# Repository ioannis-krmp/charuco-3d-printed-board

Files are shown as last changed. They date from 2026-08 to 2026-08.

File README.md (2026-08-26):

# Charuco 3D Printed Board

3D-printable CharUco board workflow with:
- PNG board generation (OpenCV ArUco/CharUco)
- CAD solid generation (FreeCAD)
- STEP export for design editing
- 2-color STL workflow for multi-material printing
- Calibration YAML for OpenCV pose estimation

## Board Spec (current project)

- Board squares: **14 x 10** (`squares_x=14`, `squares_y=10`)
- Square size: **20.0 mm**
- Marker size: **15.0 mm**
- Dictionary: **`DICT_5X5_100`**
- Physical size: **280 x 200 mm**
- Thickness: **2.5 mm**

---

## Setup (Ubuntu 24.04)

This project uses two separate Python runtimes:

- **`uv`-managed venv** — for `gen_png.py` (OpenCV) and the CadQuery scripts (`colorize_step_cq.py`, `export_glb.py`). Run these with `uv run python <script>.py`.
- **FreeCAD's own bundled Python** — for `build_step.py`, `build_stl.py`, `build_step_colored.py`, since they `import FreeCAD, Part, Mesh` (and `ImportGui`), which are not pip-installable and only exist inside FreeCAD itself. Run these with `freecadcmd <script>.py`, **not** `uv run`.

### 1) Install system dependencies

```bash
# git, if not already installed
sudo apt update
sudo apt install -y git

# FreeCAD 0.21 (provides the `freecadcmd` binary used below)
sudo add-apt-repository ppa:freecad-maintainers/freecad-stable
sudo apt update
sudo apt install -y freecad
```

> The Ubuntu 24.04 `universe` repo also ships a `freecad` package, but the PPA above is what this project was built and tested against (`FreeCAD 0.21.2`). If you already have a working FreeCAD 0.21.x install (`freecadcmd --version`), you can skip the PPA.

Install `uv` (manages the Python venv + dependencies, no system Python packages needed):

```bash
curl -LsSf https://astral.sh/uv/install.sh | sh
# then restart your shell, or: source $HOME/.local/bin/env
```

`uv` will automatically download and use Python 3.11 (pinned in `.python-version`) — you don't need to install Python yourself.

### 2) Clone and install project dependencies

```bash
git clone git@github.com:ioannis-krmp/charuco-3d-printed-board.git
cd charuco-3d-printed-board
uv sync
```

`uv sync` creates `.venv/` and installs everything from `pyproject.toml`/`uv.lock`: `opencv-contrib-python`, `cadquery`, `manifold3d`, `numpy`, `trimesh`.

### 3) Verify the install

```bash
# venv deps
uv run python -c "import cv2, cadquery; print('cv2', cv2.__version__, '| cadquery', cadquery.__version__)"

# FreeCAD
freecadcmd --version
freecadcmd -c "import FreeCAD, Part, Mesh; print('FreeCAD OK', FreeCAD.Version()[0]+'.'+FreeCAD.Version()[1])"
```

If both commands print versions without errors, you're ready to run the pipeline below.

---

## Repository Structure

Suggested layout:

```text
.
├── gen_png.py
├── build_step.py
├── build_stl.py
├── build_step_colored.py
├── colorize_step_cq.py
├── export_glb.py
├── charuco_board.yaml
├── meta.txt
├── charuco.png
├── charuco_white.step
├── charuco_black.step
├── charuco_board.step
├── charuco_board_colored.step
├── charuco_board_colored.glb
├── charuco_board_step.FCStd
├── charuco_white.stl
├── charuco_black.stl
├── pyproject.toml
├── uv.lock
├── PROJECT_HISTORY.md
└── README.md
```

> You can also place outputs in `out/` if you prefer.
>
> `pyproject.toml`/`uv.lock` pin the `uv`-managed dependencies (see [Setup](#setup-ubuntu-2404)); `PROJECT_HISTORY.md` is a narrative log of what was tried, what failed, and why — read it if you hit one of the FreeCAD/color issues below and want the backstory.

---

## Quick Start (A)

Run these from the repo root, in this order. Board parameters (`SQUARES_X`, `SQUARE_LEN_MM`, `THICK_MM`, dictionary, etc.) are hardcoded near the top of each script — edit them there if you want a different board than the [current spec](#board-spec-current-project); just keep the values consistent across all scripts and the calibration YAML.

## 1) Generate board PNG + metadata

```bash
uv run python gen_png.py
```

Reads the parameters at the top of `gen_png.py` (14×10 squares, 20mm, `DICT_5X5_100`, 4 px/mm) and produces:
- `charuco.png` — the flat board image (1120×800 px for the current spec)
- `meta.txt` — 3 lines: pixel width, pixel height, pixels-per-mm (consumed by the FreeCAD scripts below)

## 2) Build CAD-editable STEP solids

```bash
freecadcmd build_step.py
```

Converts `charuco.png` into two complementary BREP solids (`white = full_slab - black`), cleans faces with `removeSplitter()`, and exports:
- `charuco_white.step`, `charuco_black.step` — individual solids
- `charuco_board.step` — both solids in one STEP assembly
- `charuco_board_step.FCStd` — editable FreeCAD document

**This is slow** — it's building thousands of per-pixel-run boxes and fusing them with `multiFuse`. Expect several minutes for a 14×10 board; it prints `row N/H` progress and `A:`…`J:` stage markers, so it's working even when it looks stuck. Let it finish.

## 3) Build STLs for 2-color printing

```bash
freecadcmd build_stl.py
```

Same complementary-solid geometry as step 2, but meshed and exported as STL, plus its own `.FCStd`:
- `charuco_white.stl`, `charuco_black.stl`
- `charuco_board.FCStd`

Also slow for the same reason as step 2 — this rebuilds the geometry from scratch rather than reusing the STEP output.

In your slicer:
- Load both STLs
- Keep same origin/alignment (they were exported from the same coordinate system, don't re-center either one)
- Assign White filament to `charuco_white.stl`, Black filament to `charuco_black.stl`
- Use **Print sequence: By layer**

## 4) Colored visualization exports (STEP + GLB)

STEP color via FreeCAD's console (`ImportGui`) doesn't work on a headless/console build — see [Troubleshooting #3](#3-importgui--color-export-fails-in-console). The working path is CadQuery, run through `uv`, using the STEP solids from step 2:

```bash
uv run python colorize_step_cq.py   # -> charuco_board_colored.step
uv run python export_glb.py         # -> charuco_board_colored.glb
```

`.glb` is the reliable one for checking color in a browser/web viewer — see [Troubleshooting #4](#4-step-shows-no-color-in-online-viewer) for why the colored STEP may still look gray in some viewers.

Optional — `freecadcmd build_step_colored.py` also exists and will get as far as saving a colored `charuco_board_colored.FCStd`, but is **expected to fail** on its final `ImportGui.export()` call with `Cannot load Gui module in console application`; that's a known FreeCAD console limitation, not a bug in the script (see [Troubleshooting #3](#3-importgui--color-export-fails-in-console) and `PROJECT_HISTORY.md`). Use it only if you want the colored `.FCStd`; use `colorize_step_cq.py` for the colored STEP itself.

## 5) Calibration YAML

Use:

```yaml
dict_type: DICT_5X5_100
reference_frame: charuco_board
squares_x: 14
squares_y: 10
square_size: 0.020
marker_size: 0.015
```

Keep `squares_x`/`squares_y`/`square_size`/`marker_size`/`dict_type` here in sync with whatever you set at the top of `gen_png.py` (note the unit difference: mm in the script, meters in the YAML).

---

## Printing Notes

- Recommended for AMS/MMU-style color swap:
  - White base + black pattern as separate solids
  - **By layer** printing
- Add brim for flatness on large plates
- Keep bed well-leveled; this is a metrology target
- Measure printed square size with calipers and, if needed, update YAML dimensions for precise calibration scale

---

## Troubleshooting (B)

## 1) First-layer geometry conflicts (slicer errors)

**Symptom:** "Some objects are too close", "virtual bed out of bounds", or bad 2-color merge.

**Cause:** Overlapping full slabs or duplicate bottoms.

**Fix:** Use complementary solids:
- `white = full_slab - black`
- `black = pattern`
No overlap, perfect interlock.

---

## 2) FreeCAD script is very slow

**Symptom:** `multiFuse` appears stuck for minutes.

**Cause:** Thousands of pixel-run boxes.

**Fixes:**
- Let it finish (expected for large boards)
- Keep `removeSplitter()` to clean faces
- Consider faster geometry strategy (face/contour extrusions) for large designs

---

## 3) `ImportGui` / color export fails in console

**Symptom:** `Cannot load Gui module in console application.`

**Cause:** Your FreeCAD console build cannot load GUI module in headless mode.

**Fix:**
- Use CadQuery/OCP route for colorized export, or
- Do color assignment + STEP export from FreeCAD GUI.

---

## 4) STEP shows no color in online viewer

**Symptom:** STEP appears gray in https://3dviewer.net

**Cause:** Viewer limitation (many web viewers ignore STEP XDE color styling).

**Fix:**
- Verify in CAD tools (FreeCAD/Fusion/etc.)
- Use `.glb` for browser color preview

---

## 5) Charuco pose/calibration seems wrong

**Common causes:**
- `squares_x`/`squares_y` swapped
- Wrong dictionary
- Nominal vs actual printed square size mismatch

**Fix checklist:**
- Confirm `squares_x=14`, `squares_y=10`
- Confirm `DICT_5X5_100`
- Measure printed square with calipers and update YAML (meters)

---

## 6) Python script errors like "unterminated string literal"

**Cause:** Truncated paste/edit of script file.

**Fix:** Re-copy full script and verify file end before running.

---

## Versioned Parameters (Current)

- `squares_x = 14`
- `squares_y = 10`
- `square_size = 0.020` (m)
- `marker_size = 0.015` (m)
- `dict_type = DICT_5X5_100`
- `thickness = 2.5` (mm)

---

## License

If you want this reusable, add a license file (MIT/BSD recommended).

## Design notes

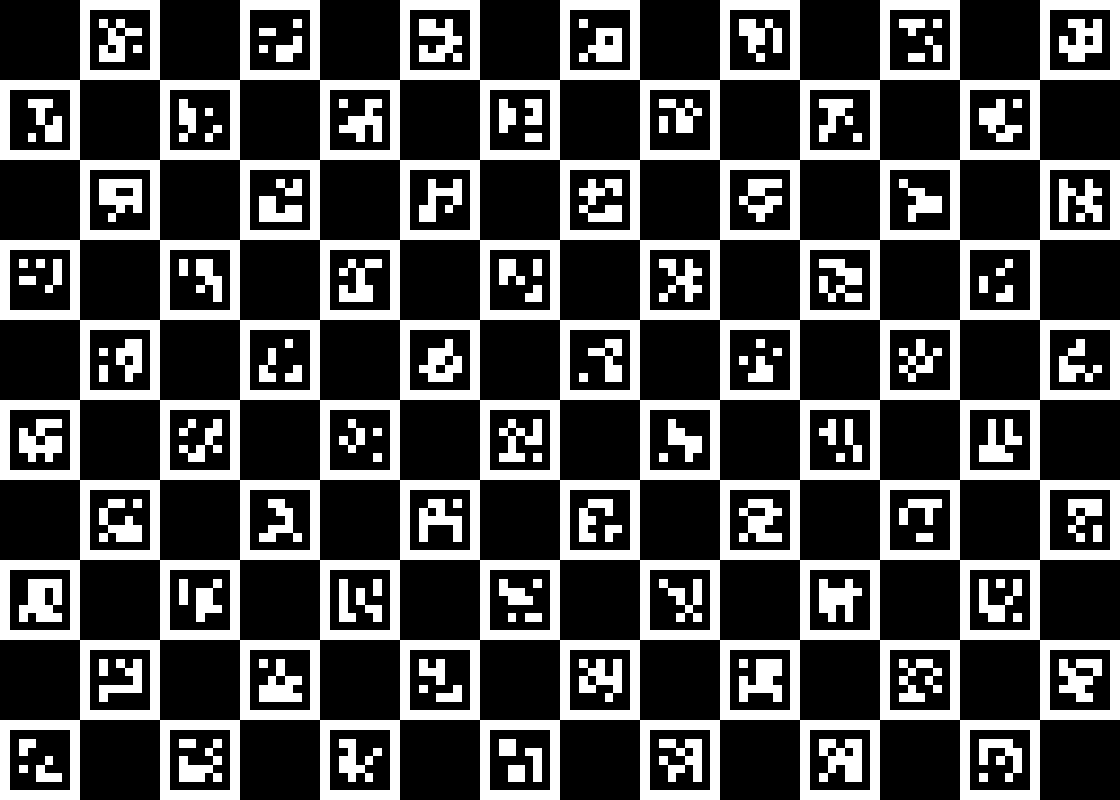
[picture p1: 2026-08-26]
charuco.png

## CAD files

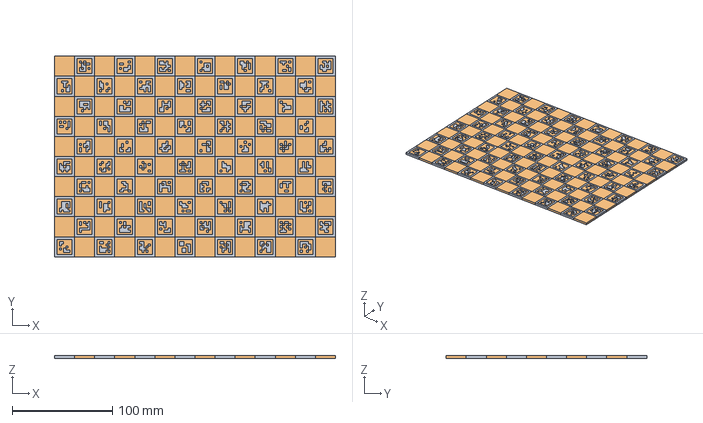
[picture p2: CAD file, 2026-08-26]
charuco_board_step.FCStd
280.0 x 200.0 x 2.50 mm
White
Black

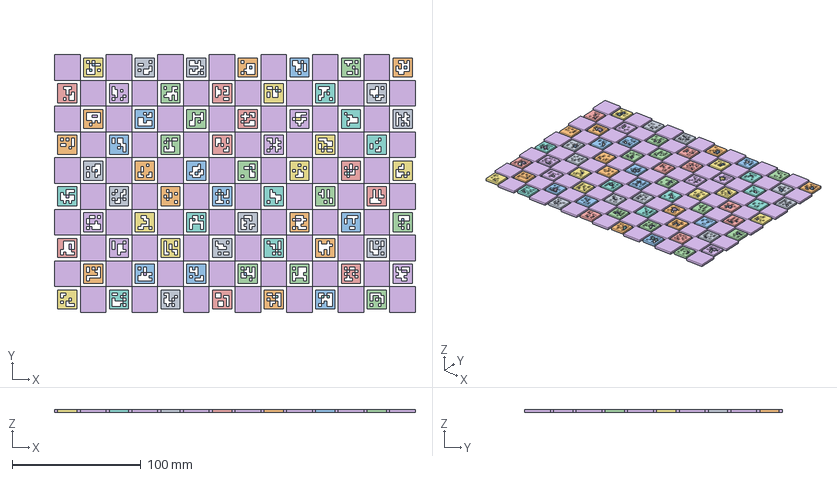
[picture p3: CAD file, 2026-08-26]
charuco_black.step
280.0 x 200.0 x 2.50 mm

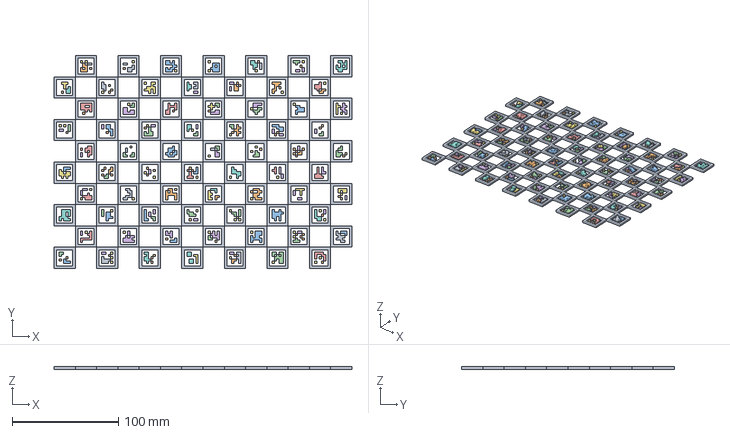
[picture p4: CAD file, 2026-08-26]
charuco_white.step
280.0 x 200.0 x 2.50 mm

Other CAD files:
charuco_board.step
charuco_board_colored.FCStd
charuco_black.stl
charuco_board.FCStd
charuco_white.stl

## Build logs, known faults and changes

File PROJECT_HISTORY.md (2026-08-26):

# Project History: Charuco 3D Printed Board (Full Process Log)

This document records the full process we followed, including what worked, what failed, and the final successful workflow for both STL and STEP outputs.

## Goal

Create a **3D-printable CharUco board** and make it usable for:
1. **Multi-color 3D printing** (white board + black markers)
2. **CAD editing/design work** (proper STEP solids)
3. **OpenCV calibration** (correct YAML parameters)

Target board:
- 14 x 10 squares
- 20 mm square size
- 15 mm marker size
- `DICT_5X5_100`
- Total size: 280 x 200 mm
- Thickness: 2.5 mm

---

## Phase 1 — Initial generation and geometry pipeline

### What we did first
- Generated board image from OpenCV CharUco setup (`gen_png.py`).
- Saved:
  - `charuco.png`
  - `meta.txt` (image width/height and pixels-per-mm)

### Approach used
- Convert PNG pixels into 3D solids using FreeCAD:
  - Identify black regions
  - Build run-length row boxes (`Part.makeBox`)
  - Fuse them into one black solid (`multiFuse`)
  - Create white base by subtraction:
    - `white = full_slab - black`

### Why this was chosen
This creates **complementary solids** (interlocking geometry), which is ideal for 2-color slicing and clean CAD export.

---

## Phase 2 — Printing geometry validation (STL)

### First STL attempt issues
We hit slicing conflicts at first (common in dual-color workflows):
- object overlap warnings
- first-layer collisions
- occasional wrong color assignment / ambiguity in slicer

### What fixed it
Using **complementary bodies** fixed all geometry conflicts:
- Black = actual marker/pattern volume
- White = slab with black volume removed

This means:
- No overlap
- No layer-0 ambiguity
- Cleaner assignment in slicer

### STL outcome
✅ `charuco_white.stl` and `charuco_black.stl` exported correctly
✅ Multi-color slicing works when print sequence is set to **By layer**
✅ Physical print dimensions match expected board footprint

---

## Phase 3 — "Proper STEP" for CAD design work

### Requirement
You asked for a **proper STEP** file suitable for CAD editing, not just rough mesh-like output.

### What we did
- Kept BREP solid workflow in FreeCAD
- Added face cleanup:
  - `removeSplitter()` on black and white shapes
- Exported:
  - `charuco_white.step`
  - `charuco_black.step`
  - `charuco_board.step` (both solids)
  - `charuco_board_step.FCStd`

### Why this matters
`removeSplitter()` merges coplanar split faces and improves editability in CAD systems.

### STEP outcome
✅ Correct dimensions confirmed
✅ Solids valid and loadable in viewers/CAD
✅ Suitable for design operations

---

## Phase 4 — Color visualization request

You asked to include colors for better visualization.

## Attempt 1: FreeCAD headless (`freecadcmd`) with object colors
- Tried setting:
  - `ViewObject.ShapeColor`
  - and exporting colored STEP
- Result: no visible color in STEP output

**Problem:** In headless console mode, color metadata handling is limited/inconsistent.

## Attempt 2: `ImportGui` in console script
- Switched to `ImportGui.export()` + `DiffuseColor`
- Result: failed with:
  - `Cannot load Gui module in console application.`

**Problem:** Your FreeCAD installation cannot load Gui module in console mode (`freecadcmd`, `freecad --console`, `freecad -c` all same limitation).

## Attempt 3: External OCC path (`pythonocc-core`)
- Tried installing with `uv add pythonocc-core`
- Result: dependency resolution failed

**Problem:** `pythonocc-core` packaging availability constraints (not straightforward via uv/pip in your environment).

## Attempt 4 (successful): CadQuery color export
- Used CadQuery assembly workflow:
  - import white STEP
  - import black STEP
  - assign colors to each part
  - export colored assets

### Result
✅ Export succeeded
✅ `charuco_board_colored.step` produced
✅ `charuco_board_colored.glb` produced
✅ `.glb` showed colors correctly in web viewer

---

## Phase 5 — Viewer confusion and final clarification

### What looked wrong
You could not see colors in `3dviewer.net` for STEP.

### Root cause
Many web STEP viewers (including 3dviewer.net in this case) do not reliably display STEP/XDE colors.

### Verification
- GLB displayed colors correctly
- Therefore color assignment/export workflow is valid
- Issue was viewer capability, not model correctness

---

## Final status (everything working)

## Geometry / CAD
✅ Proper STEP solids created
✅ Clean dimensions and thickness
✅ Editable FreeCAD files saved (`.FCStd`)

## Printing
✅ White/black STLs are correct and slicer-compatible
✅ Multi-material print workflow validated

## Visualization
✅ Colored GLB works in web viewer
✅ Colored STEP generated (viewer support may vary)

## Calibration
✅ YAML values aligned with board specification

```yaml
dict_type: DICT_5X5_100
reference_frame: charuco_board
squares_x: 14
squares_y: 10
square_size: 0.020
marker_size: 0.015
```

---

## Lessons learned / what to avoid next time

1. **Avoid overlapping dual-color solids**
   Always build complementary geometry (`white = slab - black`).

2. **Expect FreeCAD booleans to be slow on pixel-derived models**
   Large `multiFuse` is normal; patience required.

3. **Use `removeSplitter()` for CAD-friendly STEP output**
   Improves face cleanliness and editability.

4. **Do not rely on web STEP viewers for color validation**
   Use CAD tools or export GLB for web visualization.

5. **Headless FreeCAD cannot always export colored STEP**
   If GUI modules are unavailable, use CadQuery/OCP route.

6. **Script pasting can truncate files**
   Unterminated string and similar errors were caused by partial paste; always verify full file saved.

---

## Final produced files (core)

- `charuco.png`
- `meta.txt`
- `charuco_white.stl`
- `charuco_black.stl`
- `charuco_white.step`
- `charuco_black.step`
- `charuco_board.step`
- `charuco_board_colored.step`
- `charuco_board_colored.glb`
- `charuco_board_step.FCStd`
- `charuco_board_colored.FCStd`
- scripts: `gen_png.py`, `build_step.py`, `build_stl.py`, `build_step_colored.py`, `colorize_step_cq.py`, `export_glb.py`

Project completed successfully.

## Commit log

2026-08-26 Initial commit: Charuco 3D printed board pipeline, CAD/STEP exports, colored visualization, and docs
    [charuco_black.step, charuco_black.stl, charuco_board.3mf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]
2026-08-26 Add project history log; remove unused 3mf experiment and boilerplate main.py
    3MF export and main.py were never part of the documented final workflow
    (STL/STEP/colored STEP/GLB/YAML) - only leftover from early experiments.
    [charuco_board.3mf]
2026-08-26 Document full setup and usage in README: uv/FreeCAD install on Ubuntu 24.04, exact commands per pipeline stage
    Verified against the actual dev machine (Ubuntu 24.04.4, FreeCAD 0.21.2 from
    the freecad-maintainers PPA, uv 0.11.20) rather than written from memory.
